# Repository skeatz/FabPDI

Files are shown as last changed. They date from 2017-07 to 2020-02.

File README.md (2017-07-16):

## FabPDI
**DIY PDI/ISP programmer**

The thought of building a DIY PDI programmer first came to me during [Embedded Programming](http://archive.fabacademy.org/2016/fablabsingapore/students/98/exercise08.html) week in Fab Academy 2016, when Neil talked about the ATxmega16E5 microcontroller. I was itching to try it out, but lacked a PDI programmer.

After some research, I learned that I could modify a [USBasp](http://www.fischl.de/usbasp/) into a PDI programmer. The second alternative was to build an [AVRISP-MkII clone](http://www.fourwalledcubicle.com/AVRISP.php). Since I had a couple of USBasp boards, I thought "*why not?*"

My attempt at modifying my USBasp board failed and is documented in my Fab Academy [website](http://archive.fabacademy.org/2016/fablabsingapore/students/98/exercise08.html). What I lacked at that time was a [schematic diagram](images/usbasp_v2.0_sch.jpg) of my USBasp board. I soon abandoned the attempt at modifying my USBasp board due to the limited time available, but the desire to build my own PDI programmer stayed with me all the time.

Since Fab Academy 2016, I have managed to build 2 different versions of fabbable PDI programmers, which I have documented here. I have also successfully modified 2 different versions of commercial USBasp boards for PDI programming.

1. [**FabPDI-mega8**](fabpdi-mega8.md)
   * modified USBasp
   * based on ATmega8
   * uses VUSB library
   * both PDI & ISP programmer
2. [**FabPDI-t90usb**](fabpdi-t90usb.md)
   * AVRISP-MkII compatible
   * based on AT90usb162
   * uses LUFA library
   * both PDI & ISP programmer
3. [**USBasp PDI programmer**](usbasp-mods.md)
   * modified commercial USBasp boards
   * both PDI & ISP programmer

My collection of DIY and modified PDI programmer boards:
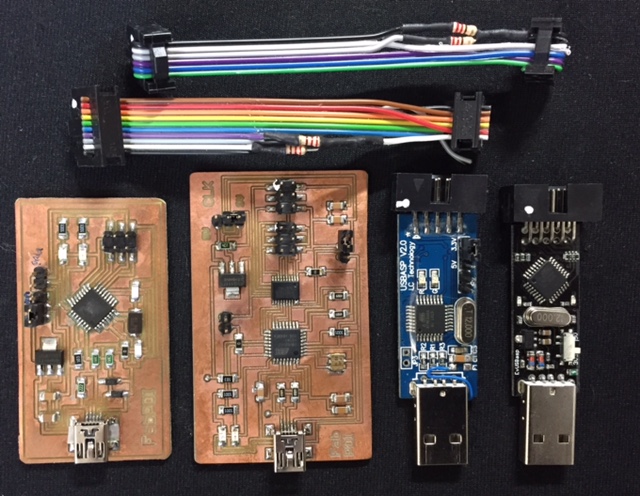
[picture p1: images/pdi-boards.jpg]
PDI-programmer collection


*PDI boards collection (from left): FabPDI-mega8, FabPDI-t90usb, USBasp v2.0 (LC Technology), USBasp (Baite)*

*Copyright (c) 2017 Steven Chew*

*MIT license*

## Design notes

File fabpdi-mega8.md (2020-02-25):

## FabPDI-mega8
The **FabPDI-mega8** programmer is based on a modified USBasp for PDI programming. The main features of this board are:
* modified USBasp
* based on ATmega8
* uses the V-USB library
* operates as both PDI & ISP programmer

You could use an ATmega88, ATmega168 or ATmega328 instead of the ATmega8, but will need to re-compile the firmware for the new microcontroller from source.

There are 3 parts to building the FabPDI-mega8 programmer:
1. Building a PDI programming cable
2. Building the FabPDI-mega8 board and uploading the modified USBasp firmware to it
3. Compiling a modified version of avrdude that recognizes the FabPDI-mega8 as a PDI programmer

My main references in building the FabPDI-mega8 programmer were articles from:
* [Szulat](http://szulat.blogspot.sg/2012/08/atxmega-programmer-for-050.html)
* [Ketturi](https://ketturi.kapsi.fi/2013/05/programming-xmega-with-usbasp-avrdude/)

and I am indebted to these authors for the information that I gleaned from their sites.

## Building a PDI Programming cable
A regular USBasp uses a 5V supply. The ATxmega series ICs operate at 3.3V, including the data pins. There are a few ways to resolve this problem:
1. Use a separate 3.3V power supply and zener diodes to limit the voltages to 3.3V
2. Ensure that our FabPDI-mega8 can switch completely (including data pins) between 5V and 3.3V operation

2 versions of the PDI programming cable can be fabricated, depending on which of the 2 approaches above is used.

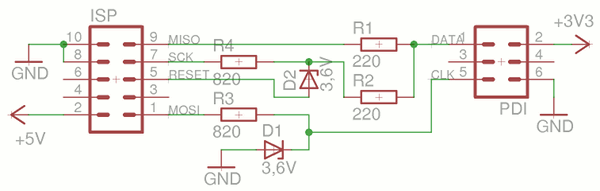
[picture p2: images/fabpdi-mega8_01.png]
FabPDI cable 5V board


*PDI programming cable for a 5V board*

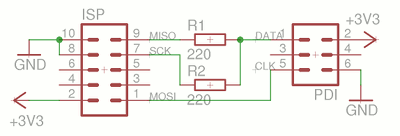
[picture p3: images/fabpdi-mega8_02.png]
FabPDI cable 3.3V board


*PDI programming cable for a 3.3V board*

For my FabPDI-mega8 board, I modified the original USBasp design such that the board can switch completely between a 5V supply and a 3.3V supply. I kept the cable short to minimize issues with noise and timing disruptions to the PDI protocol and spliced the 220 ohm resistors directly into the ribbon cable.

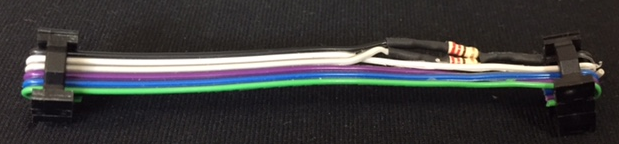
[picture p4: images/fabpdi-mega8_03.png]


A regular 6-way cable is used for ISP programming.

## Building the FabPDI-mega8 Board
### **Schematic Diagram and PCB Layout**

The schematic diagram, component layout, fab modules compatible board outline and pcb traces are shown below.

The schematic is a modified version of Thomas Fischl's [original USBasp](http://www.fischl.de/usbasp/) circuit. Component values have been modified for Fablab inventory as far as possible and the ATmega8 microcontroller switches completely between 5V and 3.3V. I opted to use a 12 MHz crystal as per Thomas's original design as I had some available. If you use a different crystal frequency, you will to change the fuse bits and clock value in the source code as well.

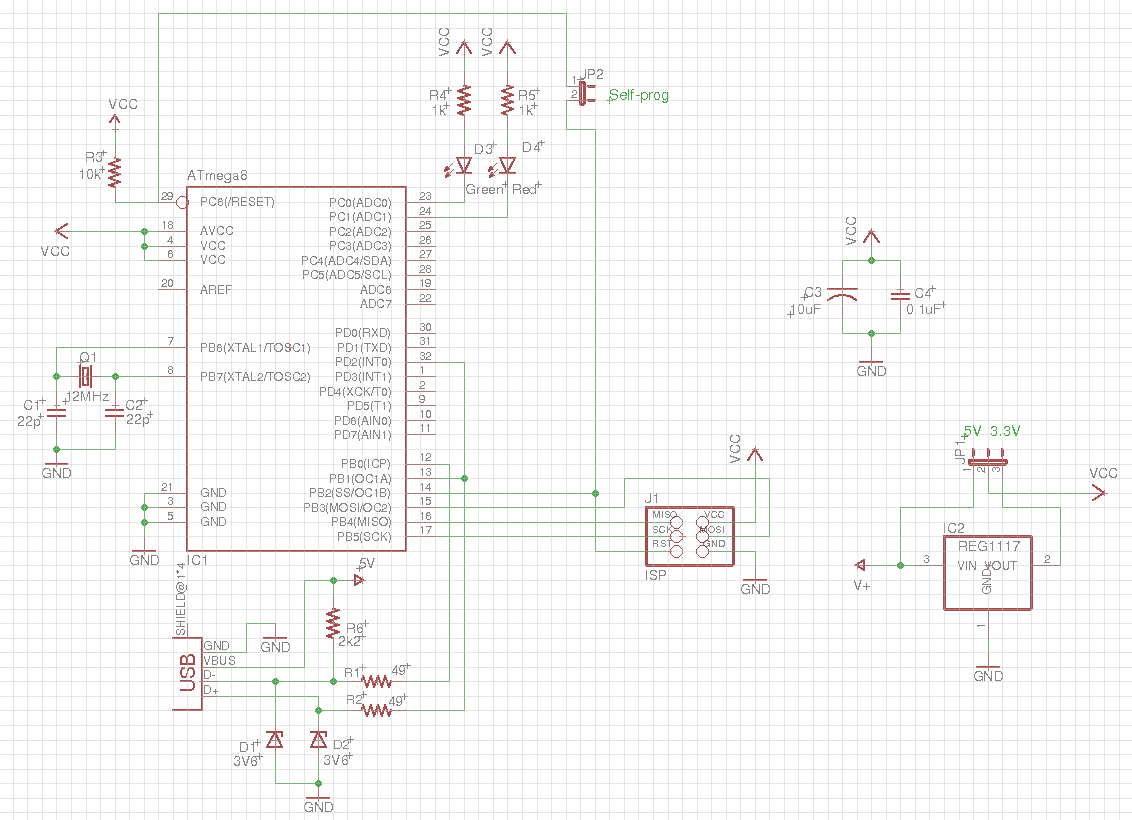
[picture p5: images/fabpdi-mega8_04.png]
FabPDI-mega8 schematic


*FabPDI-mega8 schematic*

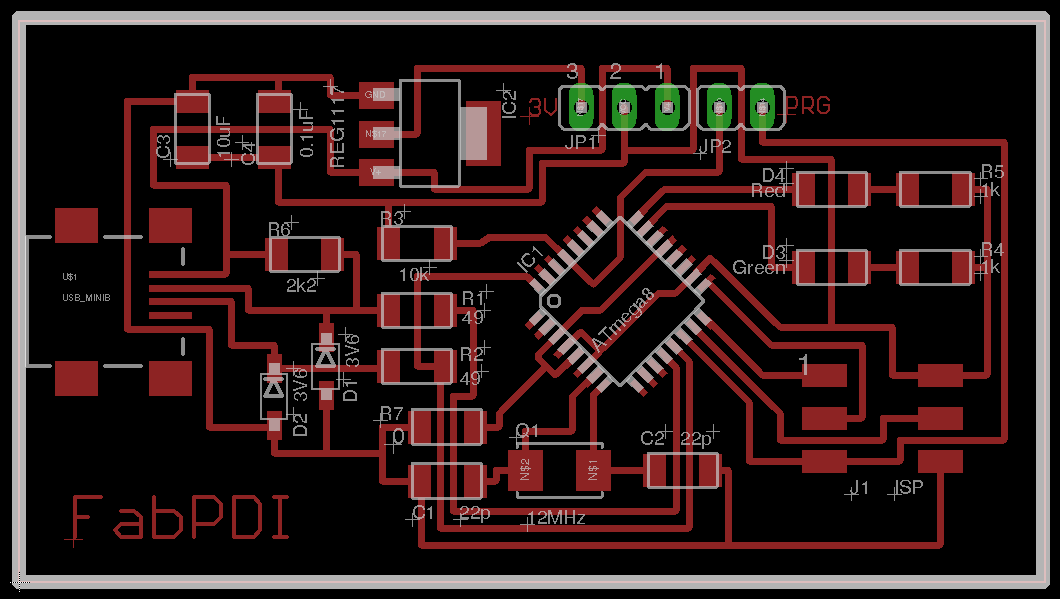
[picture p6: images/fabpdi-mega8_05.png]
FabPDI-mega8 pcb layout


*FabPDI-mega8 board layout*

Fab modules downloads (1269dpi):

* [FabPDI-mega8 board outline](images/fabpdi-mega8_outline.png)
* [FabPDI-mega8 pcb trace](images/fabpdi-mega8_traces.png)

Mill and Stuff the PCB

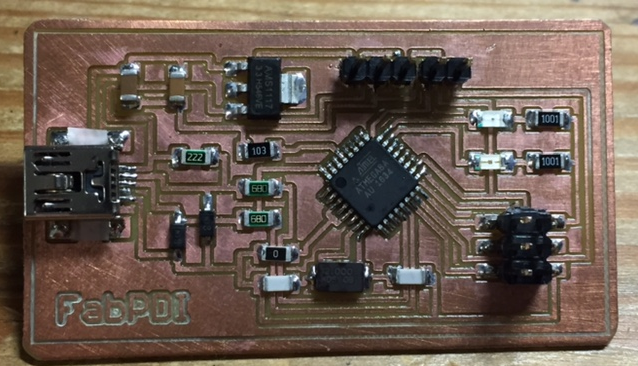
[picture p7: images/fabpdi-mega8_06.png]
FabPDI-mega8 milled & stuffed


### **Component List**

| Component | Component |
| :--- | :--- |
| 1 x ATmega8A-AU | 1 x Mini-USB |
| 1 x AMS1117-3.3 regulator | 1 x PinHD 2x3 ISP |
| 2 x 3V6 zener | 1 x PinHD 1x2 |
| 1 x LED red | 1 x PinHD 1x3 |
| 1 x LED green | 1 x 12MHz crystal |
| 1 x 10uF capacitor | 1 x 0.1uF capacitor |
| 2 x 22pF capacitor | 1 x 10k ohm R |
| 1 x 2k2 ohm R | 2 x 1k ohm R |
| 2 x 49 ohm R | 1 x 0 ohm R |

### **Programming the Firmware**
The original USBasp firmware has to be modified to support PDI programming. Szulat's [article](http://szulat.blogspot.sg/2012/08/atxmega-programmer-for-050.html) lists the steps used to modify the firmware. You basically need to do the following:

1. Download Thomas Fischl's USBasp [sourcecode](http://www.fischl.de/usbasp/usbasp.2011-05-28.tar.gz) (latest version)
2. Download the patch file at this [link](http://sz.toyspring.com/usbasp-pdi-usbaspfirmware-20120816.diff)
3. Unpack the sourcecode, apply the patch, then compile the file
4. Upload it to the FabPDI-mega8 board using another ISP programmer

To simplify the process, you can download the modified USBasp firmware for PDI programming [here](files/fabpdi-mega8/fabpdi-mega8-firmware.hex) and flash it to the board as follows:

`avrdude -c avrisp2 -p m8 -U flash:w:fabpdi-mega8-firmware.hex`
`avrdude -c avrisp2 -p m8 -U hfuse:w:0xc9:m -U lfuse:w:0xef:m`

**Note:** Remember to short the programming jumper (JP2 in my schematic) when you are flashing the firmware.

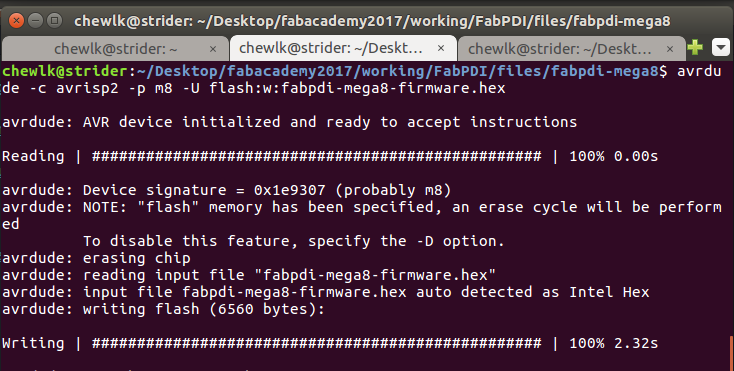
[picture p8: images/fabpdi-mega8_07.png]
Uploading firmware to FabPDI-mega8


Disconnect the ISP programmer, remove the self-programming jumper (JP2) from the FabPDI-mega8 board and reconnect it to your computer. If you have done everything correctly, the board will now identify itself on the PC. In Linux:

`lsusb`

gives

*Bus 008 Device 009: ID 16c0:05dc Van Ooijen Technische Informatica shared ID for use with libusb*

If you have gotten this far, congratulations! You are almost there. There is just one more part remaining - patching avrdude to recognize FabPDI-mega8 for PDI programming.

## Patching AVRDUDE
I followed the information in [Szulat's](http://szulat.blogspot.sg/2012/08/atxmega-programmer-for-050.html) and [Ketturi's](https://ketturi.kapsi.fi/2013/05/programming-xmega-with-usbasp-avrdude/) sites to patch avrdude for PDI programming when I first started.

The instructions from Szulat's site used avrdude version 5.11 (r1092). After compiling avrdude, I found that that version of avrdude only supported the ATxmega series A and D devices, not the series E devices which we use in Fablab. Since I didn't have ATxmega A or D devices, I could not verify if the patch worked. I also could not get the patch file to work with a newer release of avrdude, which supports the ATxmega16E5.

Ketturi's site slightly better. Following instructions at his site, I could compile avrdude under MinGW, but not in Linux. Ketturi provided a precompiled version of avrdude for Windows, but again, this was avrdude version 5.11, which did not support the ATxmega series E devices.

To cut a long story short, after a lot of research and much trial and error, I have successfully managed to compile the latest version of avrdude (version 6.3) for both Windows and Linux environments, which support the ATxmega series E devices like the ATxmega16E5 used in Fab Academy.

The compiled binaries can be download from the links below.
* [AVRDUDE v6.3 for Windows](files/fabpdi-mega8/avrdude-6.3_win32.zip)
* [AVRDUDE v6.3 for Linux](files/fabpdi-mega8/avrdude-6.3_linux.tar.gz)

To use the files, unpack the files into a subdirectory or folder. In Windows, open a command prompt window and change to that directory and run it. In Linux, open a terminal, change to the avrdude directory and run it. The FabPDI-mega8 programmer identifies itself as a usbasp device.

**Remember** - You need to use the modified programming cable for PDI programming and set the voltage selection jumper to 3.3V if you are programming an ATxmega device.

### For Windows
Unpack avrdude-6.3_win32.zip. Open a command prompt window, then change to the avrdude subdirectory. Run avrdude:

`avrdude -c usbasp -p x16e5`

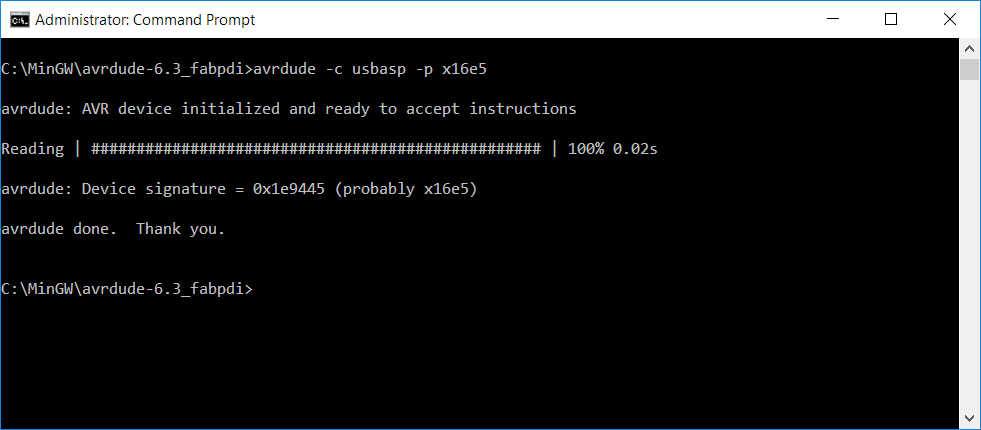
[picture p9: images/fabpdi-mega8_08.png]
FabPDI-mega8 under Windows


### For Linux
Open a terminal window. Unpack avrdude-6.3_linux.tar.gz. Change to the program directory, then run avrdude:

`tar xvzf avrdude-6.3_linux.tar.gz`
`cd avrdude-6.3`
`avrdude -c usbasp -p x16e5`

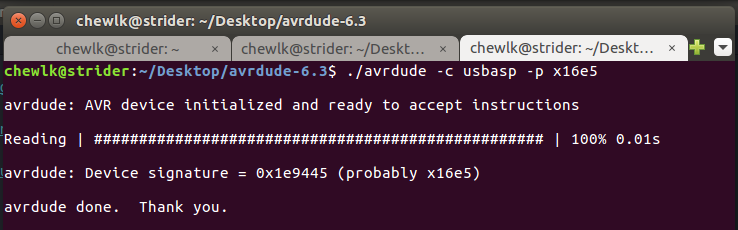
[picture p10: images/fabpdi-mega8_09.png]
FabPDI-mega8 under Linux


***Congratulations! You have built your very own FabPDI programmer!!***

## Files
* [Eagle schematic for FabPDI-mega8](files/fabpdi-mega8/fabpdi-mega8.sch)

* [Eagle pcb layout for FabPDI-mega8](files/fabpdi-mega8/fabpdi-mega8.brd)

* [Firmware for FabPDI-mega8](files/fabpdi-mega8/fabpdi-mega8-firmware.hex)

* [AVRDUDE v6.3 for Windows](files/fabpdi-mega8/avrdude-6.3_win32.zip)

* [AVRDUDE v6.3 for Linux](files/fabpdi-mega8/avrdude-6.3_linux.tar.gz)

*Copyright (c) 2017-Steven Chew*

*MIT license*

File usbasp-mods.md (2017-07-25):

## USBasp Mods for PDI programming
The [FabPDI-mega8](fabpdi-mega8.md) programmer that I built is actually a USBasp modified for PDI programming. I started out by modifying existing USBasp boards that I had, before I designed and built FabPDI-mega8. The steps here are largely similar, except that there is no need to build your own board.

I had 2 versions of the commercial USBasp programmers, which I bought from Aliexpress, a unit marked as LC Technology USBasp V2.0 and a second unit from [Baite](www.betemcu.cn). The online price for these programmers range from USD1.20 to USD1.60 for single pieces and as low as USD7.30 for 10 pcs for the LC Technology version.

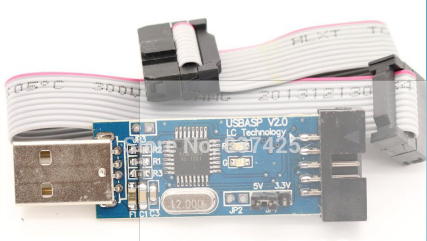
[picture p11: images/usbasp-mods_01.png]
LC Technology USBasp


*LC Technology USBasp*

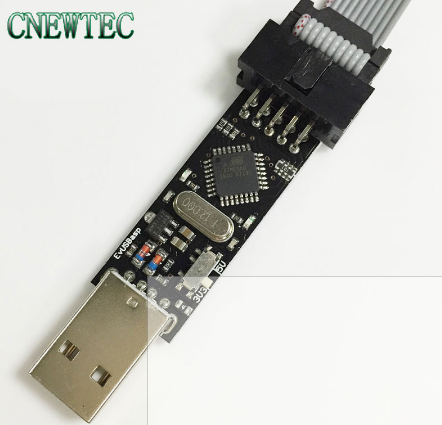
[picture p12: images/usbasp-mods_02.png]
Baite USBasp


*Baite USBasp*

The main difference between these 2 boards is that in the case of the LC Technology programmer, **the 3V jumper only the Vcc of the programming header to 3.3V. The rest of the device, including the data lines is still operating at 5V**. For the Baite programmer, the 3V switch configures the entire board (Vcc, data lines) to operate at 3.3V.

What the above paragraph implies is that you need to make hardware modifications to the LC Technology programmer, in order to use it as a PDI programmer, whereas the Baite programmer does not require any hardware modification.

There are 3 parts to building the FabPDI-mega8 programmer:
1. Building a PDI programming cable
2. Modifying the USBasp board (required for LC Technology programmer) and uploading the modified USBasp firmware to it
3. Compiling a modified version of avrdude that recognizes the FabPDI-mega8 as a PDI programmer

My main references in modifying my commercial USBasp boards for PDI programming were articles from:
* [Szulat](http://szulat.blogspot.sg/2012/08/atxmega-programmer-for-050.html)
* [Ketturi](https://ketturi.kapsi.fi/2013/05/programming-xmega-with-usbasp-avrdude/)

## Building a PDI Programming cable
A regular USBasp uses a 5V supply. The ATxmega series ICs operate at 3.3V, including the data pins. There are a few ways to resolve this problem:
1. Use a separate 3.3V power supply and zener diodes to limit the voltages to 3.3V
2. Ensure that our FabPDI-mega8 can switch completely (including data pins) between 5V and 3.3V operation

2 versions of the PDI programming cable can be fabricated, depending on which of the 2 approaches above is used.

FabPDI cable 5V board

*PDI programming cable for a 5V board*

FabPDI cable 3.3V board

*PDI programming cable for a 3.3V board*

Keep the cable short to minimize issues with noise and timing disruptions to the PDI protocol. I spliced the 220 ohm resistors directly into the ribbon cable.



A regular 6-way cable is used for ISP programming.

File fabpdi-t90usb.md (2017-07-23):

## FabPDI-t90usb
The FabPDI-t90usb programmer is a PDI/ISP programmer, based on Atmel's [AVRISP-MkII](http://www.atmel.com/tools/avrispmkii.aspx). The main features of this board are:
* based on Atmel's AVRISP-MkII
* uses the AT90usb162 microcontroller
* [LUFA library](http://www.fourwalledcubicle.com/LUFA.php) by Dean Camera
* operates as both PDI & ISP programmer

You could substitute the AT90usb162 by other members of the AT90usb family or the ATmega16U2 or higher devices, as long as it has > 16 kB memory and hardware USB support.

Since the FabPDI-t90usb board is a clone of the AVRISP-MkII, it will work directly with standard versions of AVRDUDE without any need to patch the software.

There are 2 steps involved in building the FabPDI-t90usb programmer:
1. Mill and stuff the PCB
2. Upload firmware to the board

My main references for this project were:
* [USBtiny-mkII by mdiy](http://mdiy.pl/programator-usbtiny-mkii-slim/?lang=en)
* [LUFA library & Projects](http://www.fourwalledcubicle.com/AVRISP.php)

## FabPDI-t90usb Schematic & PCB Layout
The AVRISP-MkII clone project at [fourwalledcubicle](http://www.fourwalledcubicle.com/AVRISP.php) supports PDI, ISP and TPI programming. Since I was only interested in implementing the PDI and ISP protocols, I left out the TPI programming interface, to reduce the dimensions of the PCB.

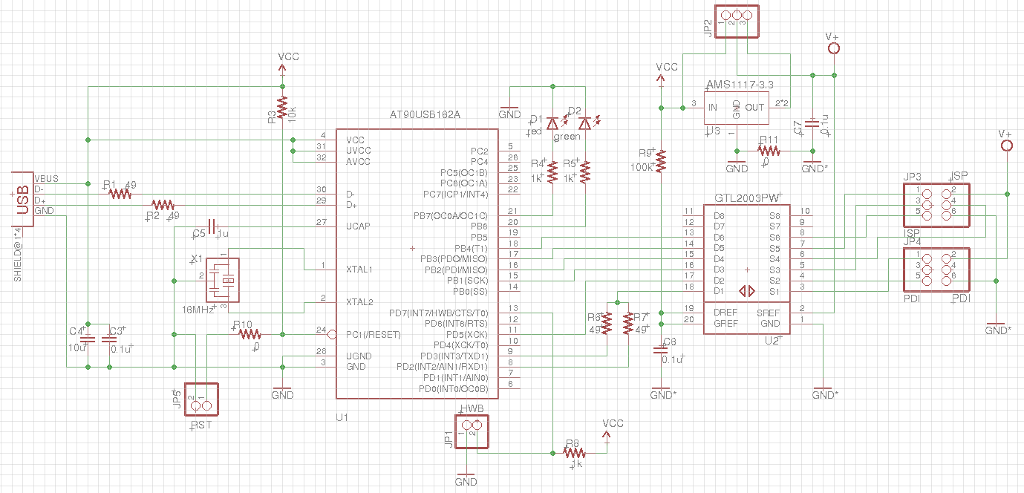
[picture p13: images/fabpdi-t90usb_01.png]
FabPDI-t90usb Schematic


*FabPDI-t90usb schematic diagram*

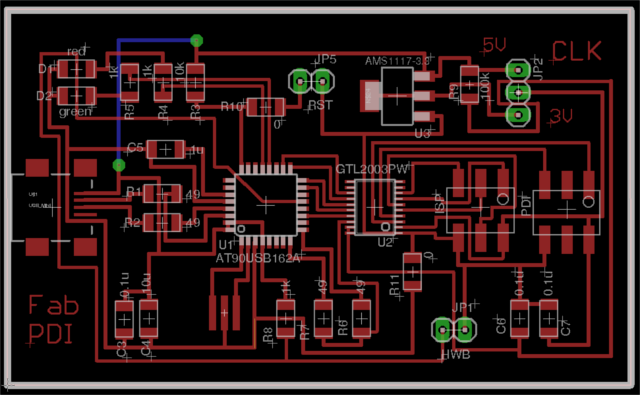
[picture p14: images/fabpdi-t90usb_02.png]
FabPDI-t90usb PCB layout


*FabPDI-t90usb pcb layout*

**Note** the use of a jumper wire at the top left of the pcb layout diagram. There are 2 other 0 ohm resistors in my design. I opted to use a jumper wire to save time, instead of trying to change the component placement and re-route the entire board.

**Tip**: when I started laying out the PCB, I did not know if I needed any 0 ohm resistors or where they should be located. To add a 0 ohm resistor in Eagle board layout, you need to de-link the PCB editor from the Schematic editor. You can do this by closing the Schematic editor. This allows you to add components in the PCB editor, but you lose the ability to do forward or backward annotation.

Fab modules downloads (1269dpi):

* [FabPDI-t90usb board outline](images/fabpdi-t90_outline.png)
* [FabPDI-t90usb pcb trace](images/fabpdi-t90_traces.png)

### Mill and stuff the pcb.

Most of the traces are 15 mil wide, except for the traces connected to the [GTL2003-PW](http://www.nxp.com/docs/en/data-sheet/GTL2003.pdf) voltage level translator. The pins on this device are very fine and close together, so care must be taken in soldering this chip.

FabPDI-t90usb completed board

*Completed FabPDI-t90usb board*

### Testing the board
After milling & stuffing the FabPDI-t90usb, connect it to a USB port. In Windows, check *Device Manager* to verify that the board is correctly detected by the system. In Windows, the FabPDI-t90usb identifies itself as an AT90USB162 device. In Linux, enter the command ***lsusb*** in a terminal screen. You should see a new device called ***at90usb162 DFU***.

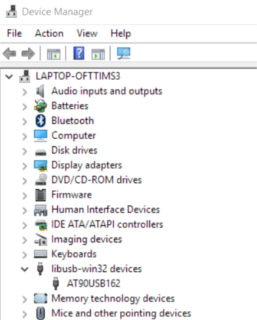
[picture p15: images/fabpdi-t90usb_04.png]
FabPDI-t90usb in Windows Device Manager


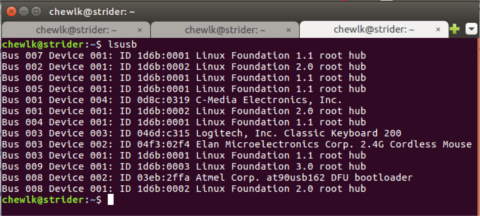
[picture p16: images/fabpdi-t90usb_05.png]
FabPDI-t90usb in Linux


## Component List
| Components | Components |
| :--- | :--- |
| 1 x AT90usb162 | 1 x Mini-USB |
| 1 x GTL2003PW | 2 x PinHD 2x3 ISP |
| 1 x AMS1117-3.3 regulator | 2 x PinHD 1x2 HW, RST |
| 1 x 16 MHz crystal | 1 x PinHD 1x3 |
| 1 x LED red | 1 x LED green |
| 1 x 10uF capacitor | 1 x 1uF capacitor |
| 3 x 0.1uF capacitor | 2 x 22pF capacitor |
| 1 x 100k ohm R | 1 x 10k ohm R |
| 3 x 1k ohm R |  4 x 49 ohm R |

### Update
I have since revised my PCB layout to make it a bit smaller and easier to mill on our Fablab standard 3" x 2" copper blanks. I did this by shifting the placement of some of the components and changing the location of one of the 0 ohm resistors. The revised schematic & pcb layout are below.

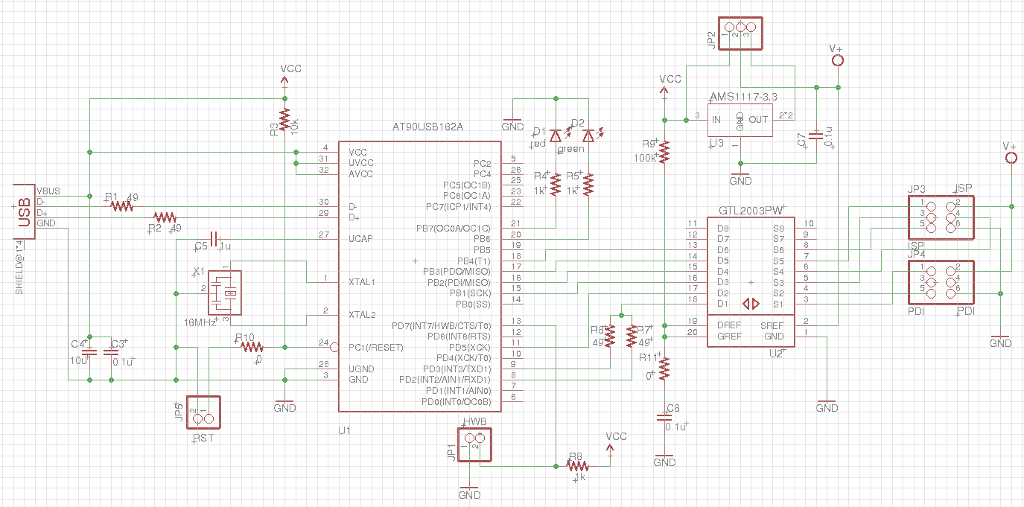
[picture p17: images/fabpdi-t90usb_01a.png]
FabPDI-t90usb revised schematic


*Revised schematic diagram*

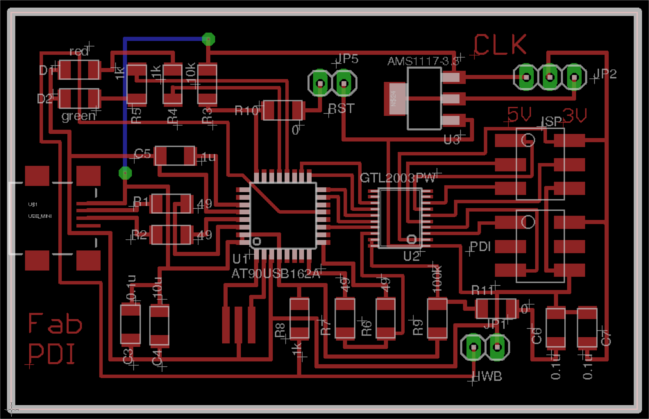
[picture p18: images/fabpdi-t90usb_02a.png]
FabPDI-t90usb revised PCB layout


*Revised pcb layout*

Fab modules download (1269dpi):
* [FabPDI-t90usb board outline](images/fabpdi-t90usb_outline.png)
* [FabPDI-t90usb pcb trace](images/fabpdi-t90usb_traces.png)

## Programming the firmware
### For Windows
The FabPDI-t90usb is a DFU class device and can be programmed via the DFU protocol. Download and install the Atmel [FLIP](http://www.atmel.com/tools/flip.aspx) software. The software requires Java Runtime Environment. 2 versions of the software are available at the Atmel site - with and without JRE. I opted to install the version with JRE, as the installation would then take care of all dependencies and environment variables required.

After the software is installed, install the DFU drivers from the \Program Files\Atmel\Flip 3.4.7\usb folder. Start FLIP, click on the **"CHIP"** icon and select at90usb162 from the list. Then click on the **"usb cable"** icon, select **USB** and **OPEN**. FLIP should detect the programmer.

To program the board, jumper the **HWB** pins. Short the **RST** pins momentarily. The board will start in bootloader mode. If the AT90usb162 is brand new (empty), it will automatically start in bootloader mode.

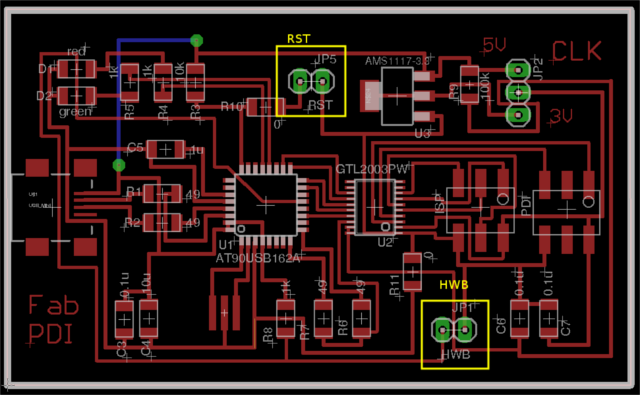
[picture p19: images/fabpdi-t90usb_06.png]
FabPDI-t90usb jumper positions


*Board showing jumper locations*

Download the pre-compiled [firmware](files/fabpdi-t90usb/fabpdi-t90usb_firmware.hex). Click on the **"Open Book"** and load the firmware. In the left column of the FLIP window, check the **"Erase"**, **"Program"** and **"Verify"** checkboxes. Click the **RUN** button. After the firmware has been uploaded to the board, disconnect and reconnect it. Alternatively, just short the **RST** pins. The two LEDs should light up and then the red LED will remain ON. The FabPDI-t90usb is ready for use.

The board should now show up as AVRISP-MkII in Devce Manager.

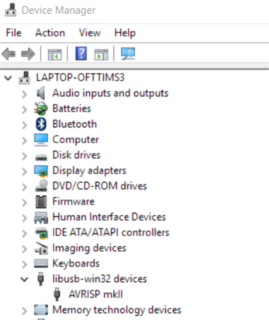
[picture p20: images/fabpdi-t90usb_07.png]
FabPDI-t90usb board after programming


*FabPDI-t90usb after uploading firmware*

Congratulations!

### For Linux
I have tried 2 different ways of programming the FabPDI-t90usb board in Linux - using the open-source [dfu-programmer](https://dfu-programmer.github.io/) and Atmel's [FLIP](http://www.atmel.com/tools/flip.aspx) programming software.

**Using DFU-programmer**

To install DFU programmer in Ubuntu, in a terminal window, type:

`sudo apt-get install dfu-programmer`

Connect the FabPDI-t90usb board to a usb port. In terminal, type:

`lsusb`

The AT90usb162 device should show up in the listing:
`Bus 008 Device 044: ID 03eb:2ffa Atmel Corp. at90usb162 DFU bootloader`

If you cannot find a similar listing, the device may not be connected in DFU mode. Check that the **HWB** jumper is set and short the **RST** pins momentarily.

Download the [firmware](files/fabpdi-t90usb/fabpdi-t90usb_firmware.hex) for FabPDI-t90usb. Open a terminal and change to the directory where the file has been saved.

Ensure that the AT90usb162 has been erased prior to programming:

`dfu-programmer at90usb162 erase`

Upload the FabPDI-t90usb firmware to the onboard flash memory:

`dfu-programmer at90usb162 flash fabpdi-t90usb_firmware.hex`

Disconnect the board, remove the **HWB** jumper and reconnect it to a usb port. The two LEDs should light up, then the red LED will remain ON. The FabPDI-t90usb is ready for use.

In a terminal window, type:

`lsusb`

The FabPDI-t90usb board should appear as an Atmel AVRISP-mkII device.

`Bus 008 Device 045: ID 03eb:2104 Atmel Corp. AVR ISP mkII`

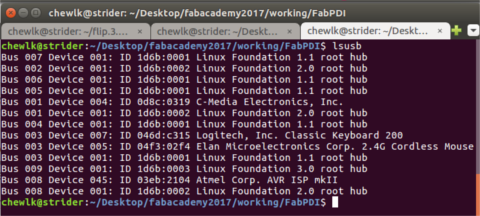
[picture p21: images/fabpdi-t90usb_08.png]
FabPDI-t90usb in Ubuntu


*FabPDI-t90usb in Ubuntu*

**Using Atmel FLIP**

Using Atmel's FLIP programmer in Ubuntu was a somewhat more complicated affair, as the FLIP is a 32-bit software and requires 32-bit Java Runtime Environment (JRE), whereas my Ubuntu environment is 64-bit.

You first need to download the Atmel [FLIP](http://www.atmel.com/images/flip_linux_3-2-1.tgz) software. You will also need 32-bit [JRE](http://www.java.com/en/download/linux_manual.jsp).

Extract both JRE and FLIP. In my case, I put FLIP in my home directory and JRE in /usr/lib/jvm/jre1.8.0_131. In terminal, type:

```
tar xvzf flip_linux_3-2-1.tgz -C /home/<user>/
sudo tar xvzf jre-8u131-linux-i586.tar.gz -C /usr/lib/jvm/
```

I also had a number of missing x32 dependencies for FLIP, which I needed to install:

```
sudo apt-get install libxrender1:i386
sudo apt-get install libxtst6:i386
sudo apt-get install libxi6:i386
```

To run FLIP in Ubuntu, I also had to set the environment variables:

```
export JAVA_HOME=/usr/lib/jvm/jre1.8.0_131
export FLIP_HOME=home/<user>/flip3.2.1/bin
export USB_DEVFS_PATH=/dev/bus/usb
```

You also need to enable non-root access to the USB device by adding the user to the dialout group:

`sudo usermod -a -G dialout <user>`

To run FLIP:

```
cd ~/flip.3.2.1/bin
./flip.sh
```

The rest of the steps are the same as using FLIP in Windows, which I have documented above. Make sure that the FabPDI-t90usb board is set to DFU mode (**HWB** jumper, momentarily short **RST** pins):

1. Select target device > at90usb162
2. Select a communications medium > USB
3. Load Hex file > [fabpdi-t90usb_firmware.hex](files/fabpdi-t90usb/fabpdi-t90usb_firmware.hex)
4. Check the **Erase**, **Program** and **Verify** checkboxes
5. Click the **Run** button and wait for the firmware to be uploaded.
6. Set the board back to normal mode (disconnect **HWB** jumper, reset the board)

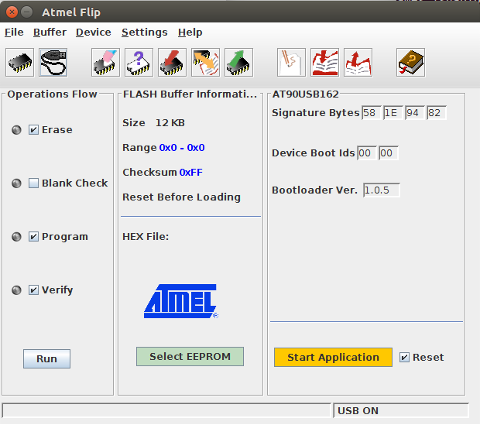
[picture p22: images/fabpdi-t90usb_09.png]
FabPDI-t90usb FLIP in Ubuntu


*Atmel's FLIP programmer in Ubuntu*

Once the firmware has been successfully uploaded to FabPDI-t90usb, it should appear as an Atmel AVRISP-mkII device:

`Bus 008 Device 045: ID 03eb:2104 Atmel Corp. AVR ISP mkII`

Congratulations! You have made yourself a PDI/ISP programmer.

## Testing the Programmer
Make sure that FabPDI-t90usb is operating in normal (non-DFU) mode. Open a command prompt window in Windows or terminal if using Linux. Connect your board to FabPDI-t90usb using the PDI header for ATxmega devices and the ISP header for ATtiny and ATmega devices.

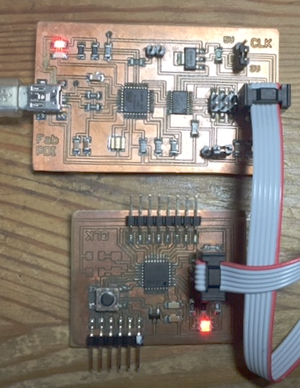
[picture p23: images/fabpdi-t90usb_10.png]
FabPDI-t90usb as PDI programmer


*FabPDI-t90usb as a PDI programmer*

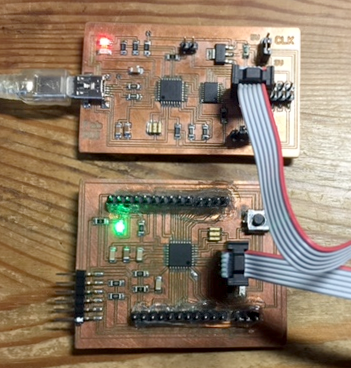
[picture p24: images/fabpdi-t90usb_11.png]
FabPDI-t90usb as ISP programmer


*FabPDI-t90usb as an ISP programmer*

 Using avrdude to detect my ATxmega16E5 Hello Board with FabPDI-t90usb:

 `avrdude -c avrispmkii -p x16e5`

Using avrdude to detect my ATmega328p arduino compatible board:

 `avrdude -c avrispmkii -p m328p`

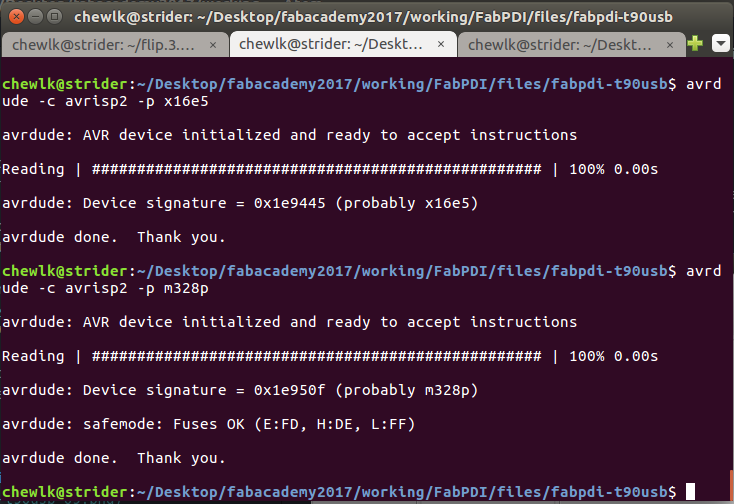
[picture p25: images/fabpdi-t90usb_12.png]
FabPDI-t90usb with avrdude
 

*FabPDI-t90usb with avrdude*

Have fun with your new PDI/ISP programmer!

## Files
* [Eagle FabPDI-t90usb schematic (v1)](files/fabpdi-t90usb/fabpdi-t90usb_v1.sch)
* [Eagle FabPDI-t90usb pcb layout (v1)](files/fabpdi-t90usb_v1.brd)
* [Eagle FabPDI-t90usb schematic (v1.1)](files/fabpdi-t90usb/fabpdi-t90usb_v1.1.sch)
* [Eagle FabPDI-t90usb pcb layout (v1.1)](files/fabpdi-t90usb/fabpdi-t90usb_v1.1.brd)
* [Firmware (for 16MHz crystal/resonator)](files/fabpdi-t90usb/fabpdi-t90usb_firmware.hex)

*Copyright (c) 2017 Steven Chew*

*MIT license*

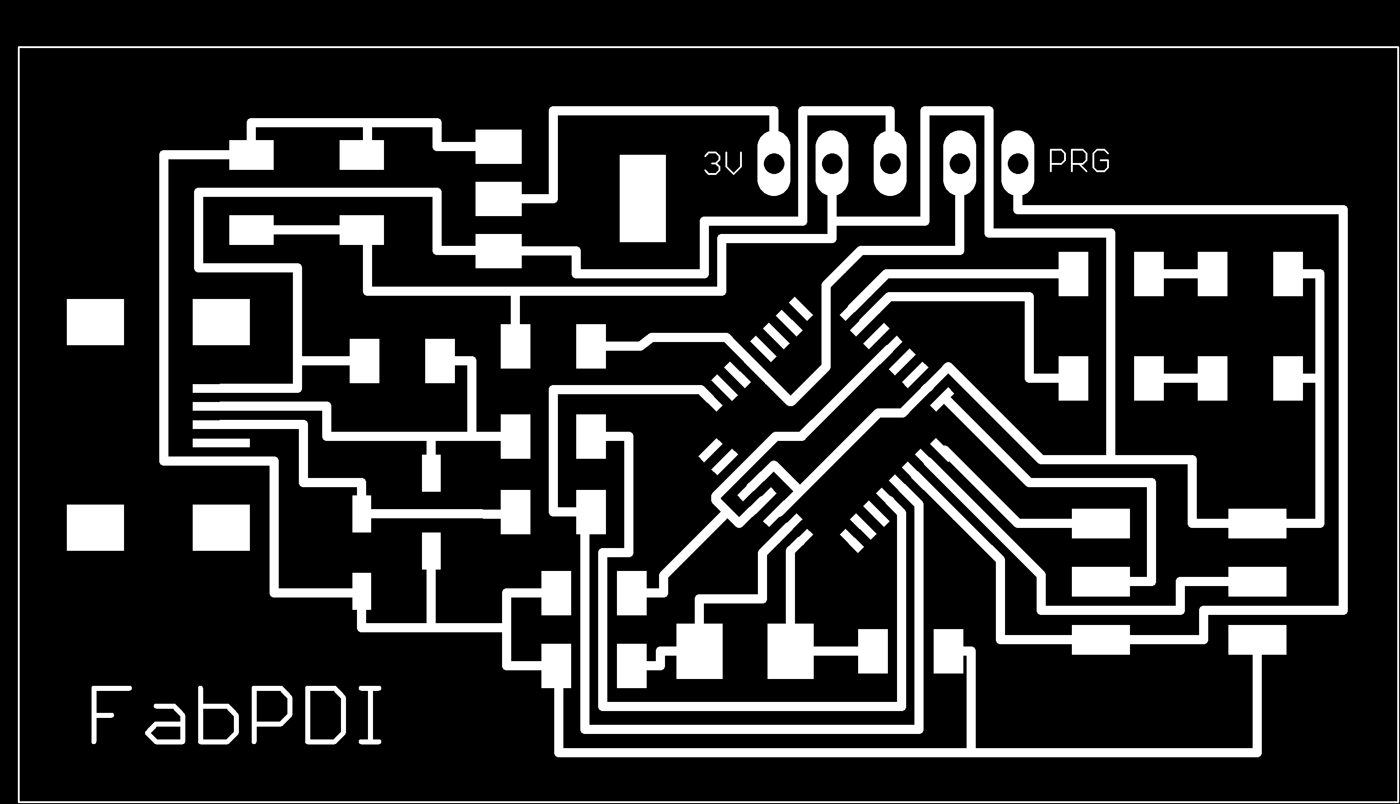
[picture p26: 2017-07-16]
images/fabpdi-mega8_traces.png

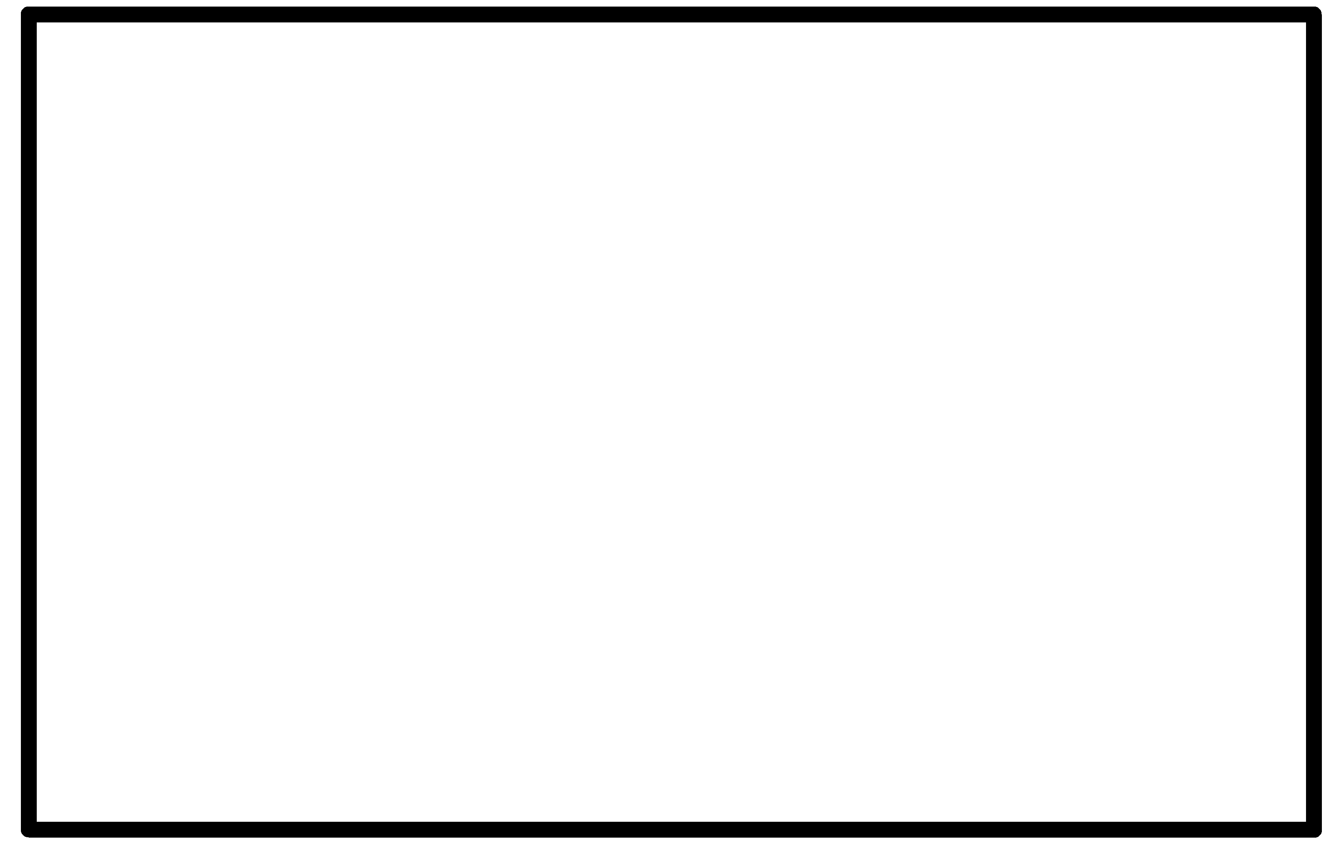
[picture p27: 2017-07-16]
images/fabpdi-t90usb_outline.png

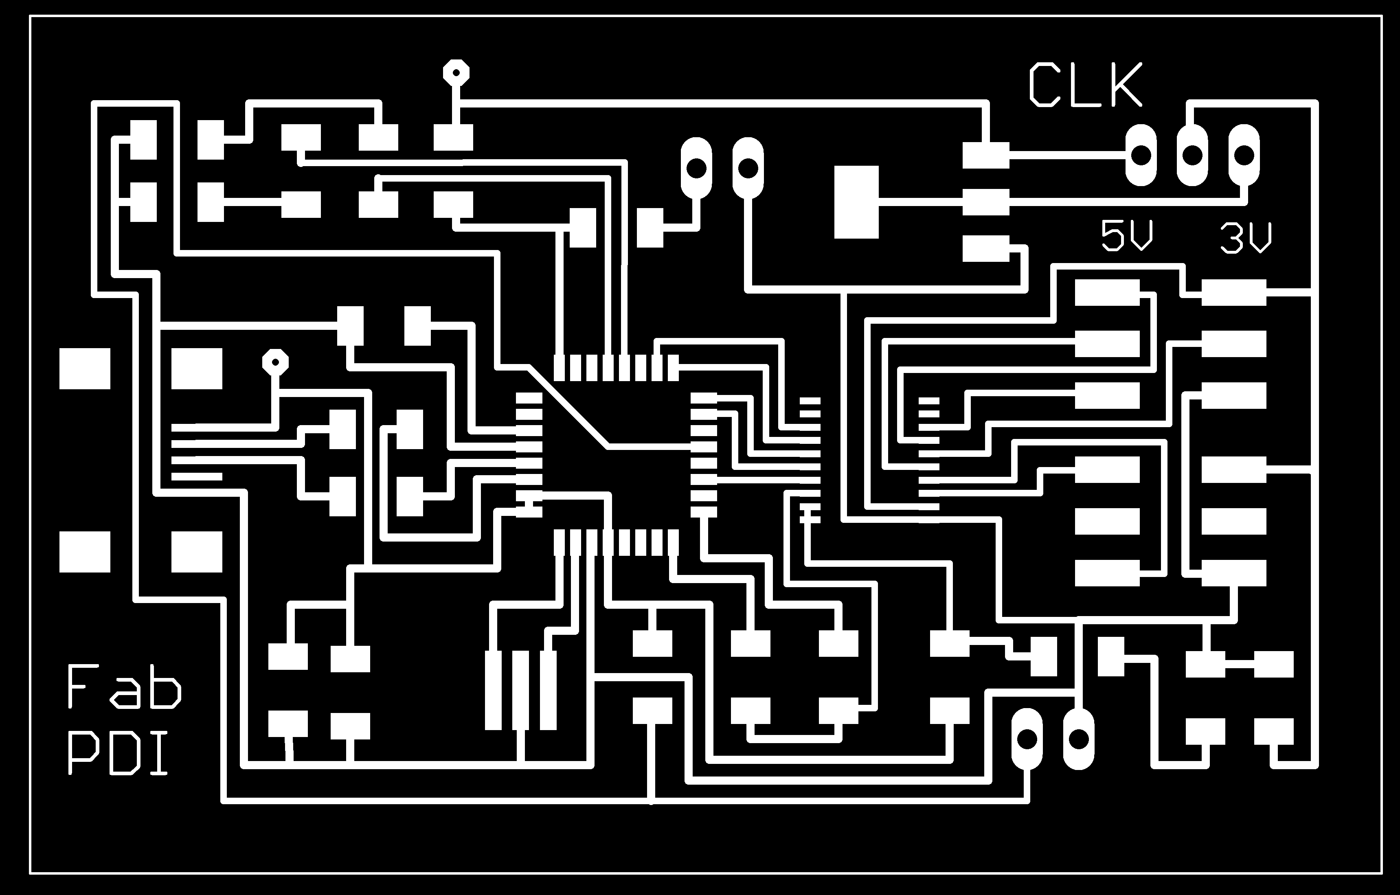
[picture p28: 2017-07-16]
images/fabpdi-t90usb_traces.png

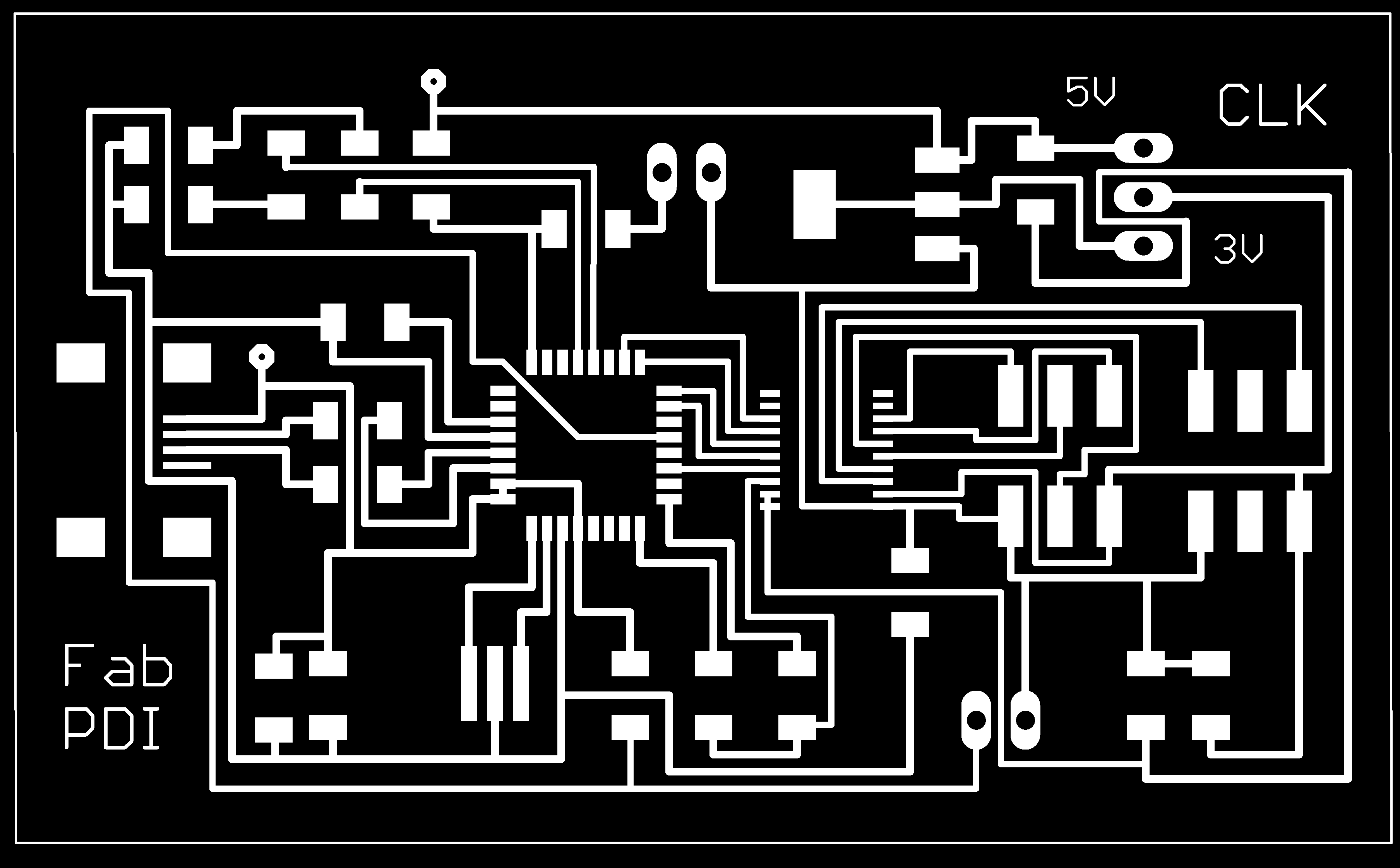
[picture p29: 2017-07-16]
images/fabpdi-t90_traces.png

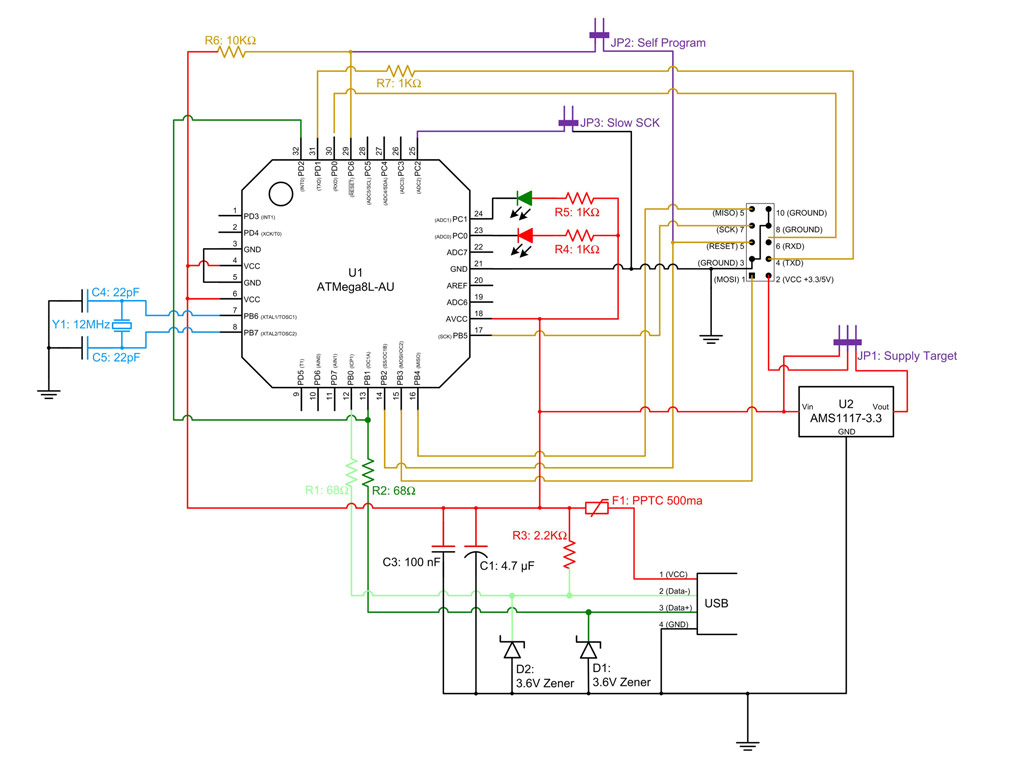
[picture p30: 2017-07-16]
images/usbasp_v2.0_sch.jpg

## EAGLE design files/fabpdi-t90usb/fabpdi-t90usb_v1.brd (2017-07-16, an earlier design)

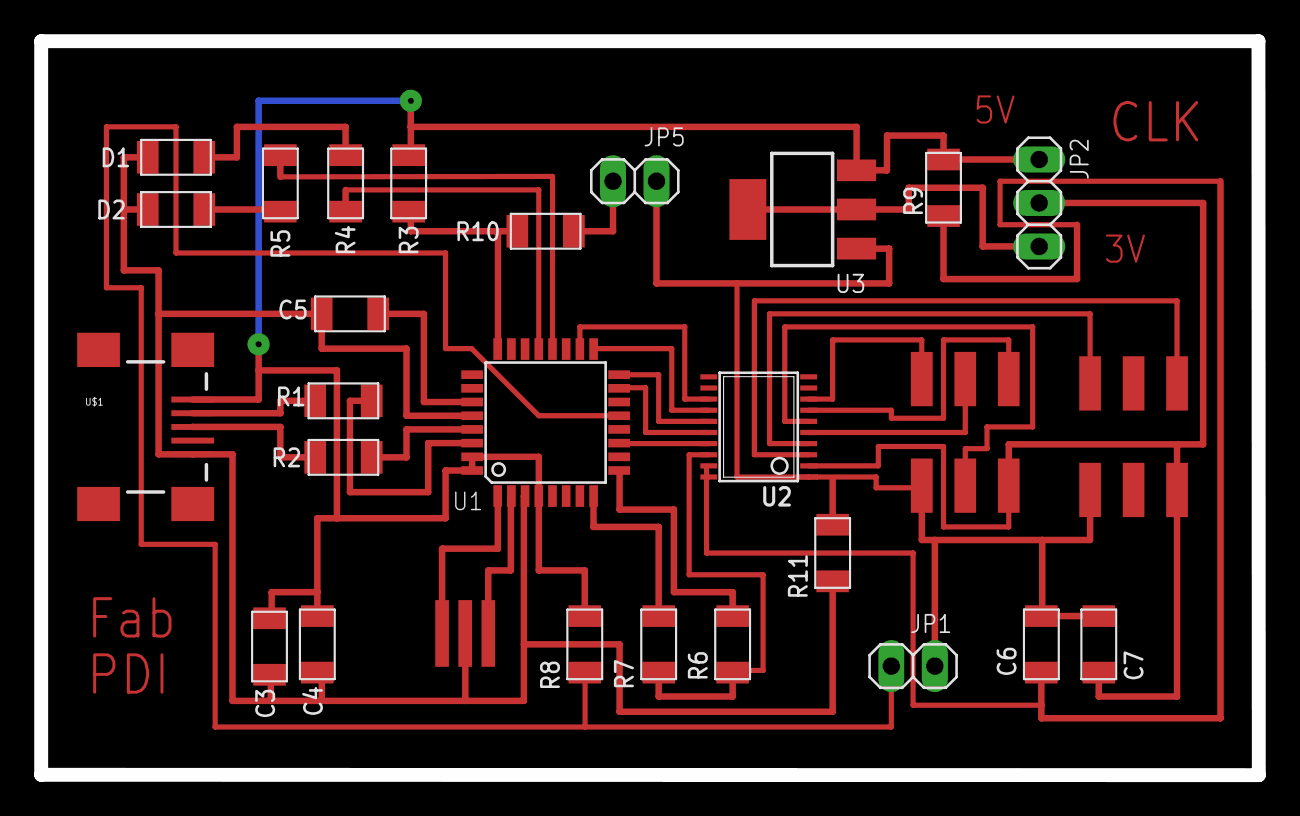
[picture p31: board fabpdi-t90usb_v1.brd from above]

Board: 2 copper layers, 71.1 x 42.9 mm, 28 parts (0 on the bottom side), 34 nets.

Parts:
C3, C6, C7: 0.1u; C1206FAB
C4: 10u; C1206FAB
C5: 1u; C1206FAB
D1: red; LED1206FAB
D2: green; LED1206FAB
JP1, JP5: 1X02
JP2: 1X03
JP3: ISP; 2X03SMD-FAB
JP4: PDI; 2X03SMD-FAB
R1, R2, R6, R7: 49; R1206FAB
R3: 10k; R1206FAB
R4, R5, R8: 1k; R1206FAB
R9: 100k; R1206FAB
R10, R11: 0; R1206FAB
U1: AT90USB162A; TQFP32-08
U2: GTL2003PW; TSSOP20
U3: AMS1117-3.3; SOT-223
U$1: USB_MINI
X1: 16MHz; EFOBM

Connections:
GND: C3.1, C4.1, C5.1, D1.2, D2.2, U1.3, U1.28, U$1.GND, X1.2
unnamed: R4.1, U1.21
unnamed: C5.2, U1.27
unnamed: U1.1, X1.1
unnamed: U1.2, X1.3
unnamed: R2.1, U$1.D+
unnamed: R2.2, U1.29
unnamed: R1.1, U$1.D-
unnamed: R1.2, U1.30
unnamed: R3.1, R10.2, U1.24
unnamed: R5.1, U1.20
unnamed: D1.1, R4.2
unnamed: D2.1, R5.2
unnamed: U1.11, U2.17
unnamed: R6.1, U1.9
unnamed: R7.1, U1.8
unnamed: JP1.2, R8.1, U1.13
unnamed: R6.2, R7.2, U2.18
unnamed: U1.15, U2.16
unnamed: U1.16, U2.15
unnamed: U1.17, U2.14
unnamed: U1.18, U2.13
unnamed: C6.2, R9.1, U2.20
unnamed: JP3.1, U2.7
unnamed: JP2.3, U3.2, U3.TER
unnamed: JP3.3, U2.5
unnamed: JP3.4, U2.6
unnamed: JP3.5, U2.8
unnamed: JP4.5, U2.4
unnamed: JP4.1, U2.3
unnamed: JP5.1, R10.1
S$1: C6.1, C7.1, JP1.1, JP3.6, JP4.6, JP5.2, U2.1, U3.1
V+: C7.2, JP2.2, JP3.2, JP4.2, U2.2
VCC: C3.2, C4.2, JP2.1, R3.2, R8.2, R9.2, U1.4, U1.31, U1.32, U3.3, U$1.VBUS

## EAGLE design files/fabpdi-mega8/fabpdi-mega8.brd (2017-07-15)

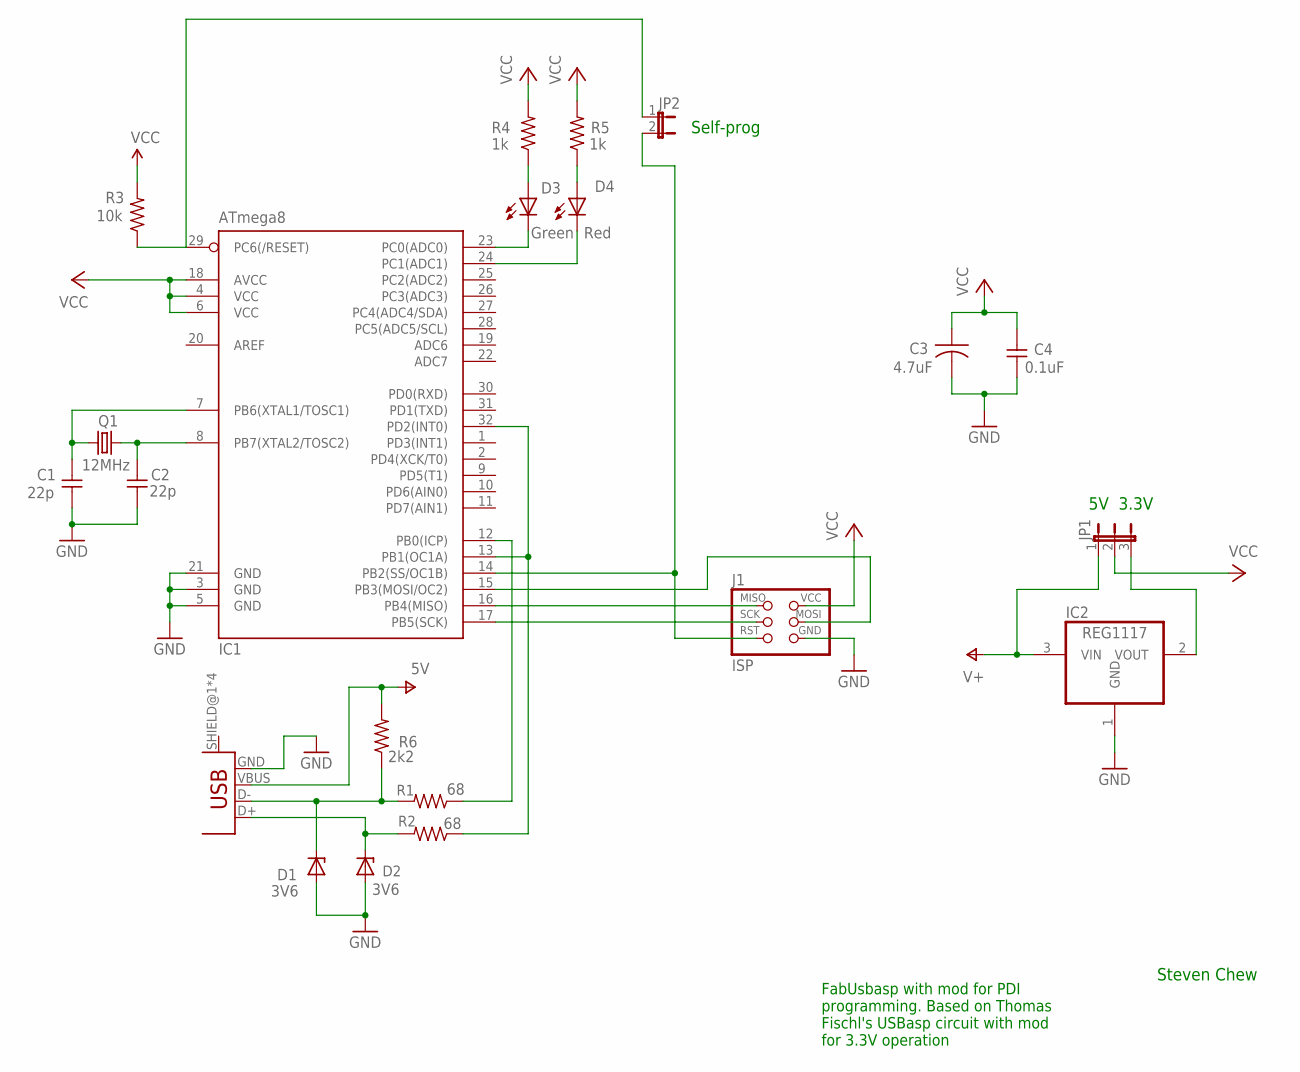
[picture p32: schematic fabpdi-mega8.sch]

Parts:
C1, C2: 22p; C1206FAB
C3: 4.7uF; C1206FAB
C4: 0.1uF; C1206FAB
D1, D2: 3V6; SOD123
D3: Green; LED1206FAB
D4: Red; LED1206FAB
IC1: ATmega8; TQFP32-08THIN
IC2: REG1117; SOT223
J1: ISP; 2X03SMD
JP1: JP2E; JP2
JP2: JP1E; JP1
Q1: 12MHz; 2-SMD-5X3MM
R1, R2: 68; R1206FAB
R3: 10k; R1206FAB
R4, R5: 1k; R1206FAB
R6: 2k2; R1206FAB
U$1: USB_MINIB

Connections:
GND: C1.1, C2.1, C3.2, C4.1, D1.ANODE, D2.ANODE, IC1.3 (GND), IC1.5 (GND), IC1.21 (GND), IC2.1 (GND), J1.6 (GND), U$1.GND
unnamed: C2.2, IC1.8 (PB7(XTAL2/TOSC2)), Q1.P$2 (2)
unnamed: C1.2, IC1.7 (PB6(XTAL1/TOSC1)), Q1.P$1 (1)
unnamed: IC1.12 (PB0(ICP)), R1.1
unnamed: D1.CATHODE, R1.2, R6.1, U$1.D-
unnamed: D2.CATHODE, R2.2, U$1.D+
unnamed: D3.2 (C), IC1.23 (PC0(ADC0))
unnamed: IC1.16 (PB4(MISO)), J1.1 (MISO)
unnamed: IC1.17 (PB5(SCK)), J1.3 (SCK)
unnamed: IC1.15 (PB3(MOSI/OC2)), J1.4 (MOSI)
unnamed: IC1.29 (PC6(/RESET)), JP2.1, R3.1
unnamed: D3.1 (A), R4.1
unnamed: D4.2 (C), IC1.24 (PC1(ADC1))
unnamed: D4.1 (A), R5.1
unnamed: IC1.14 (PB2(SS/OC1B)), J1.5 (RST), JP2.2
unnamed: IC1.13 (PB1(OC1A)), IC1.32 (PD2(INT0)), R2.1
unnamed: IC2.2 (VOUT), JP1.3
V+: IC2.3 (VIN), JP1.1, R6.2, U$1.VBUS
VCC: C3.1, C4.2, IC1.4 (VCC), IC1.6 (VCC), IC1.18 (AVCC), J1.2 (VCC), JP1.2, R3.2, R4.2, R5.2

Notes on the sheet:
FabUsbasp with mod for PDI programming. Based on Thomas Fischl's USBasp circuit with mod for 3.3V operation
Steven Chew
Self-prog
5V 3.3V

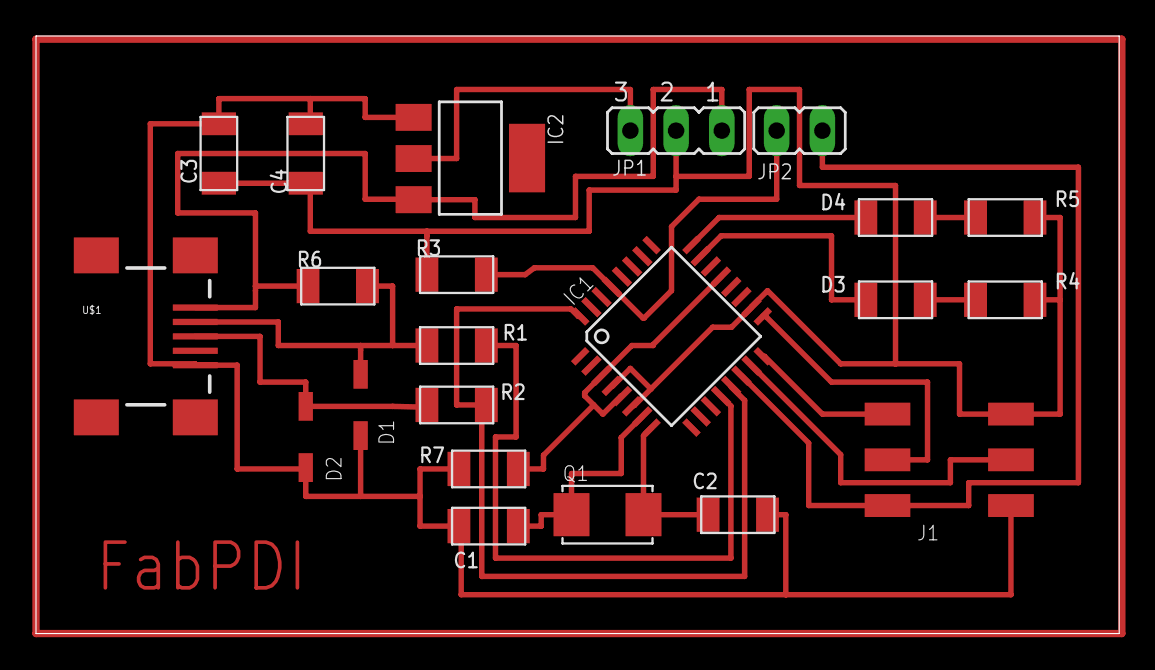
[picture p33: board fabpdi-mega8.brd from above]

Board: 2 copper layers, 60.2 x 33.2 mm, 22 parts (0 on the bottom side), 19 nets.

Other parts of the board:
R7: 0; R1206FAB

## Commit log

2017-07-15 added eagle files
    [fabpdi-mega8.brd, fabpdi-mega8.sch, fabpdi-t90usb_v1.1.brd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]
2017-07-16 labelled boards collection
2017-07-16 updated t90 design files
    [fabpdi-t90usb_v1.1.brd, fabpdi-t90usb_v1.1.sch, fabpdi-t90usb_v1.brd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]

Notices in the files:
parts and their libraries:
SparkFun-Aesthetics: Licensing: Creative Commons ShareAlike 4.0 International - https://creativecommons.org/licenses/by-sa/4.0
